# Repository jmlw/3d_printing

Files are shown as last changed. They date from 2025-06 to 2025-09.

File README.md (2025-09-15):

# 3D Printing

This repository is intened to primarily house mods, custom STLs, print profiles, possibly configuration, etc. for my 3D printer(s).

**This repository is povided as-is with no warranty or guarantee. Use at your own risk.**

## Mods

### [ArmoredTurtle BoxTurtle](https://github.com/ArmoredTurtle/BoxTurtle)

#### [Guidler](mods/ArmoredTurtle/BoxTurtle/Extruder)

Modified guidler built-in support to include a branch that touches the print bed ensuring better stability of the support rather than relying on floating printed bridges remaining in place and resucing the chance of a failed print. I found this to be much more reliable and was able to easily batch them in a single print.

### [Dragon Burner Cutter](https://github.com/chirpy2605/voron/tree/main/V0/Dragon_Burner_Cutter)

#### [Cutter Trigger](mods/Dragon_Burner_Cutter)

Custom trigger arm for the Dragon Burner Cutter to work for a Voron Trident using the Dragon Burner toolhead with the Dragon Burner Cutter and MGN9H X Gantry mount.

### [Sherpa Mini](https://github.com/Annex-Engineering/Sherpa_Mini-Extruder)

#### [Sherpa Mini Filament Sensor with ECAS](mods/Annex-Engineering/Sherpa_Mini-Extruder)

Modifies the Sherpa Mini Housing Core to include a filament sensor using a D2F switch and 4mm ball bearing as well as include an ECAS04 fitting to retain the bowden tube for use with multi-material units.

Annex Engineering licence also applies to mods for Annex-Engineering projects: https://github.com/Annex-Engineering/ANNEX-Engineering-License-Agreement

### [Crossbow Filament Cutter](https://github.com/DW-Tas/Crossbow-Filament-Cutter)

#### [Sherpa Mini Riser for Crossbow Filament Cutter](mods/DW-Tas/Crossbow-Filament-Cutter/sherpa_mini_riser)

Provides a spacer which allows Crossbow Filament Cutter using the Crossbow Cutter Holder to fully actuate with a Sherpa Mini mounted on it.

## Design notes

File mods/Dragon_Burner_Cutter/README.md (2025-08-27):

# Trident and v2.4 Trigger arm for Dragon Burner Cutter

This is a trigger arm for use on my Trident 300 (LDO kit) using a Dragon Burner with the [MGN9H X Carriage from chirpy2605 Alternative Voron Mounts](https://github.com/chirpy2605/voron/blob/main/general/Alternative_Voron_Mounts/Modified_Mounts/V1_V2/STLs/MGN9H/MGN9H_X_Carriage_Lite_lugs.stl)

The available trigger arm for the Dragon Burner Cutter sat much too high on my printer so this is a much shorter one that will sit just above the front idler hight.

The trigger can be used on either side (mirror it as necessary) in the front. It might also work in the back though that is untested. I find that I need 20mm of travel to fully depress the Dragon Burner Cutter so factor that in with the placement. With standard front idlers on a Trident the trigger will be about 21mm back.

### BOM

- 1 M5 roll in nut (recommended over a drop in T-Nut)
- 1 M5 x 10 BHCS (SHCS may work but may also benefit from a washer)

### Print Settings

Use standard Voron print settings

### STLs

[Dragon Burner Cutter Trigger](stls/dragon_burner_cutter_trigger_trident.stl)

### Images

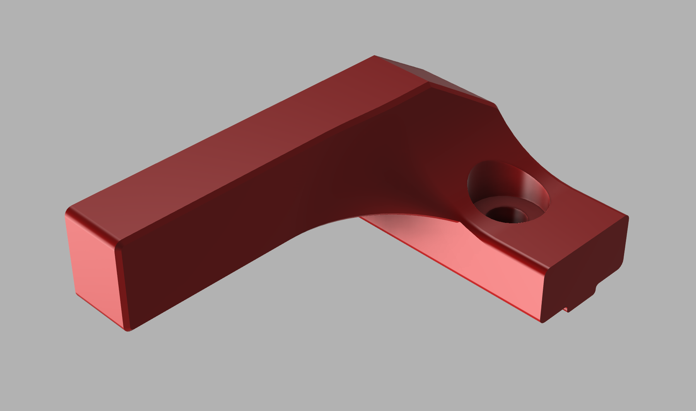
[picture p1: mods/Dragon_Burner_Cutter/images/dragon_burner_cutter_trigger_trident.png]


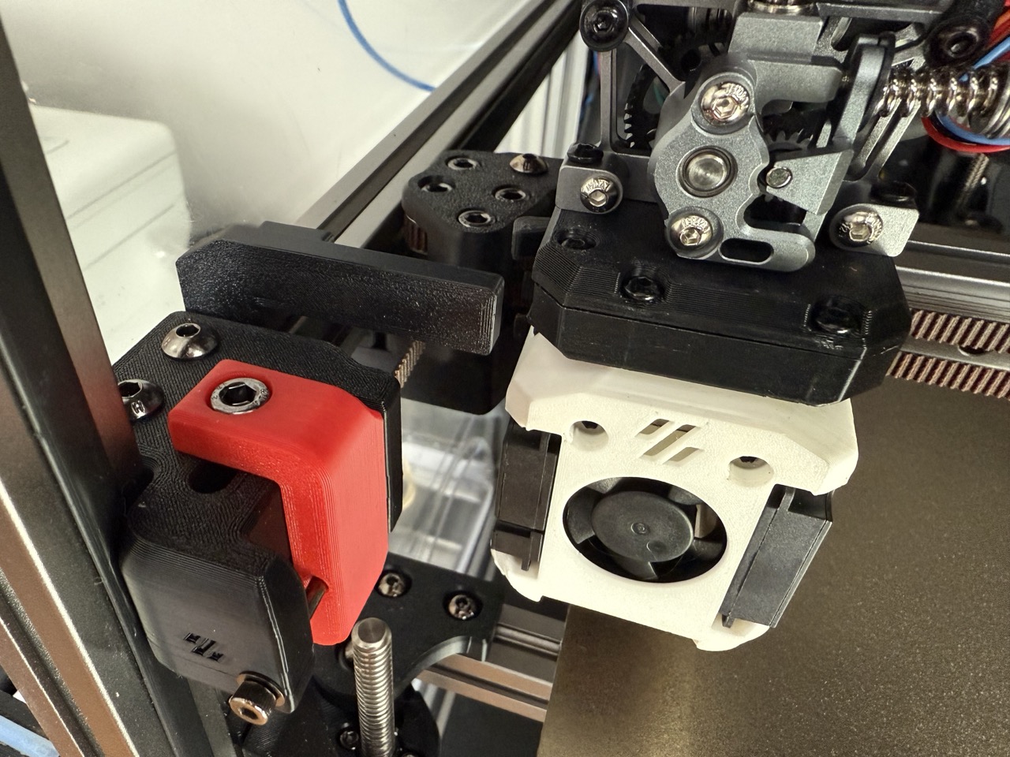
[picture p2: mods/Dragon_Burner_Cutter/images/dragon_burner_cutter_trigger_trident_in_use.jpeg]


### Changelog
2025-08-27 - stl and cad updated to give clearance for x gantry joints and make the full trigger arm beefier to reduce deflection

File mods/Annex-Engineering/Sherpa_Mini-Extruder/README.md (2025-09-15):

# [Sherpa Mini Extruder](https://github.com/Annex-Engineering/Sherpa_Mini-Extruder)

## [Housing Core with Filament Sensor and ECAS](housing_core)

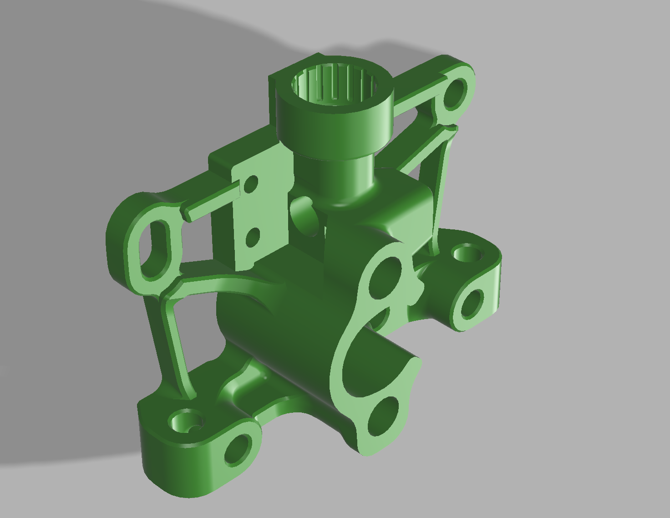
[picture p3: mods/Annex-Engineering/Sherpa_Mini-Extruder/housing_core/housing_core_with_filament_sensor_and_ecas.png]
housing core with filament sensor and ecas


This remix was created specifically to enable adding a pre-extruder toolhead filament sensor and ECAS connector without adding significant height. Bowden path also supported from the ECAS connector down into the body to ensure that MMU units like ArmoredTurtle BoxTurtle will not have obstructions when feeding filament during filament swaps. So far this design been reliable for 100's of swaps and has reliably detected issues with filament load/unload and filament runout.

### Print Settings

Print in ABS or ASA at recommended settings from Annex Engineering Sherpa Mini repo. No supports needed, 45º overhang above the D2F switch location, fits all standard Sherpa parts, no additional replacements needed.

### Standard Sherpa Mini BOM plus:

- D2F switch (or D2F-L with lever removed)
- 2x M2x10 self-tapping screws to hold switch
- 4mm Ball Bearing for sensor
- ECAS press fit connector

> The Annex Engineering License also applies: https://github.com/Annex-Engineering/ANNEX-Engineering-License-Agreement

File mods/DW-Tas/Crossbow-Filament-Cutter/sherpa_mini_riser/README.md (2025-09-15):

# [Crossbow Filament Cutter](https://github.com/DW-Tas/Crossbow-Filament-Cutter)

## Sherpa Mini Mount Spacer

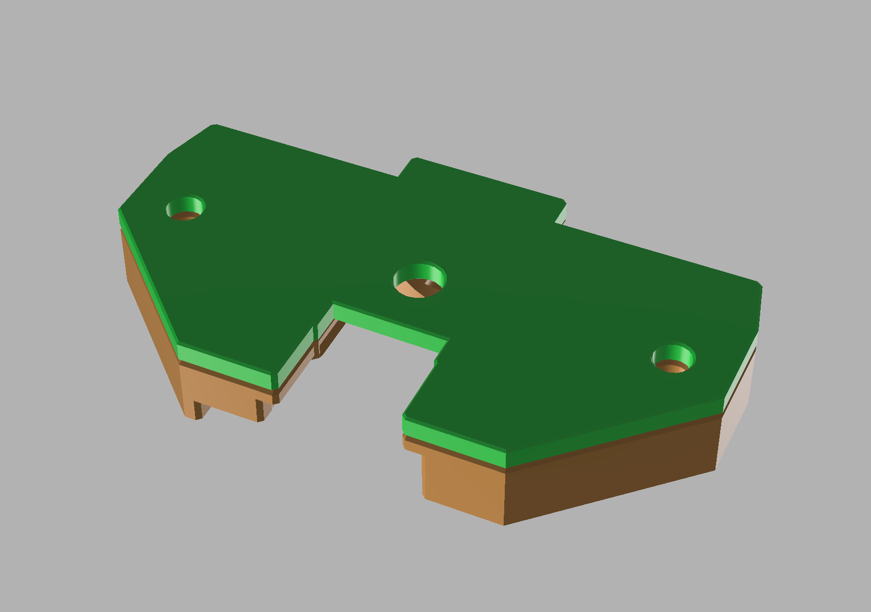
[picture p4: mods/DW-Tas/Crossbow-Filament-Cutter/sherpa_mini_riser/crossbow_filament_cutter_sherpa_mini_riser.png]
mount spacer


The Crossbow Filament Cutter has STLs available to mount the cutter to a Dragon Burner either above the standard Sherpa Mini pattern mount or in place of the sherpa pattern mount with the custom cowl provided. The Shepra Mini (printed or CNC) does not have enough clearance from the top of the [Crossbow cutter holder](https://github.com/DW-Tas/Crossbow-Filament-Cutter/blob/main/STL/Dragon%20Burner%20example/Crossbow%20cutter%20holder%20-%20WW-BMG%20(Sherpa-Mini%20spacing%29%20-%20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 to the bottom of the Sherpa Mini preventing the cutter from fully actuating.

The Sherpa Mini Mount Spacer simply sits between the cutter holder and Sherpa Mini providing enough clearance to fully actuate the cutter without interfering or requireing modification of the Sherpa Mini. A small bowden tube segment should fully pass from the Sherpa Mini through the spacer and to the top of the cutter holder.

BOM:

- No additional hardaware required
- May need ~3mm longer screws to mount Sherpa mini + Spacer + Crossbow Filament Cutter Holder

Print settings:

- Standard Voron print settings (4 walls, 40% gyroid infill, 4 top and bottom layers, 0.2mm layer height, ABS or ASA)

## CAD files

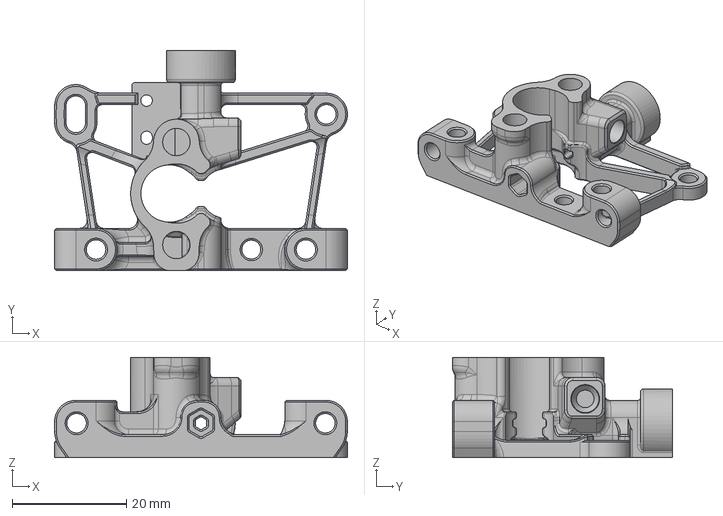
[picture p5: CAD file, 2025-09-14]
mods/Annex-Engineering/Sherpa_Mini-Extruder/housing_core/housing_core_std^housing_sherpa_mini_a3_r17_FDM_with_filament_sensor_and_ecas.step
51.2 x 38.5 x 17.5 mm

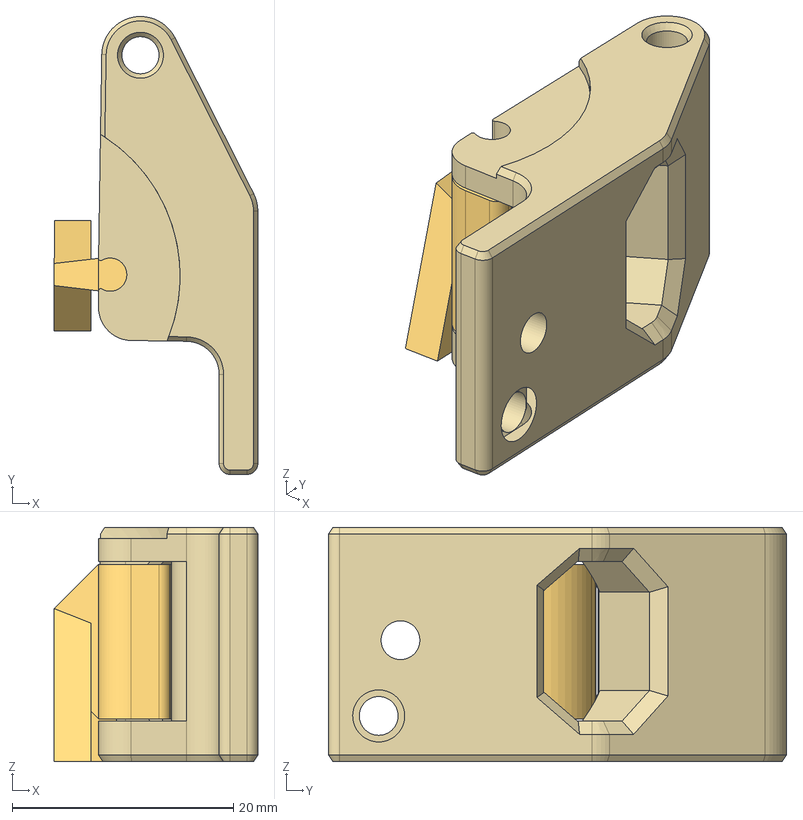
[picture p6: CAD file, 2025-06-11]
mods/ArmoredTurtle/BoxTurtle/Extruder/[a]_guidler_x4_enhanced_custom_support.step
18.4 x 41.4 x 21.2 mm

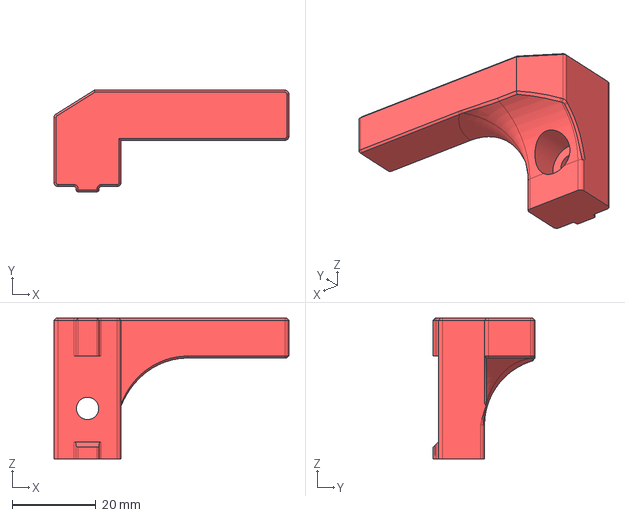
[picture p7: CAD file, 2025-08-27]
mods/Dragon_Burner_Cutter/cad/dragon_burner_cutter_trigger_trident.step
56.0 x 24.2 x 33.5 mm

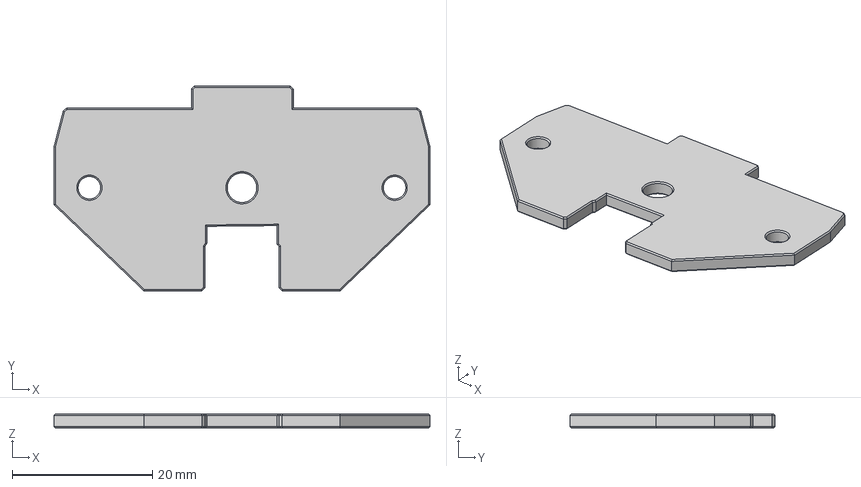
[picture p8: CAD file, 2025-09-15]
mods/DW-Tas/Crossbow-Filament-Cutter/sherpa_mini_riser/crossbow_filament_cutter_sherpa_mini_riser.step
53.6 x 29.2 x 2.00 mm

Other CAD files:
mods/ArmoredTurtle/BoxTurtle/Extruder/[a]_guidler_x4_enhanced_custom_support.stl
mods/DW-Tas/Crossbow-Filament-Cutter/sherpa_mini_riser/crossbow_filament_cutter_sherpa_mini_riser.stl
mods/Dragon_Burner_Cutter/cad/dragon_burner_cutter_trigger_trident.f3d
mods/Dragon_Burner_Cutter/stls/dragon_burner_cutter_trigger_trident.stl

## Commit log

2025-06-11 mod(boxturtle): include improved pre-supported guilder
    [[a]_guidler_x4_enhanced_custom_support.step, [a]_guidler_x4_enhanced_custom_support.stl]
2025-07-09 mod(dragonBurnerCutter): add trigger arm for dragon burner cutter
    [dragon_burner_cutter_trigger_trident.f3d, dragon_burner_cutter_trigger_trident.step, dragon_burner_cutter_trigger_trident.stl]
2025-08-27 tweak(dragon_burner_cutter_trigger): raise arm to give clearance for stock trident X gantry joints and BHCS protruding above, make trigger arm beefier to reduece deflection
    [dragon_burner_cutter_trigger_trident.f3d, dragon_burner_cutter_trigger_trident.step, dragon_burner_cutter_trigger_trident.stl]
2025-09-14 mod(sherpa_mini): include modified Sherpa Mini housing core with filament sensor and ecas04 fitting
    [housing_core_std^housing_sherpa_mini_a3_r17_FDM_with_filament_sensor_and_ecas.step]
2025-09-15 mod(crossbow_cutter): add riser to increase space between crossbow cutter and sherpa mini
    [crossbow_filament_cutter_sherpa_mini_riser.step, crossbow_filament_cutter_sherpa_mini_riser.stl]
2025-09-15 add image for sherpa mini with filament sensor and ecas
